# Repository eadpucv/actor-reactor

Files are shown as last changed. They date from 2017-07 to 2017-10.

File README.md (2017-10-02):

# Actor Reactor

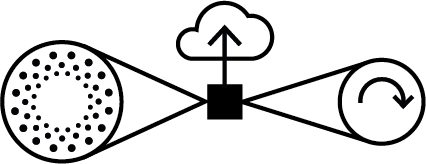
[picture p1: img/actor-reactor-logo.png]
Logo Actor Reactor


Actor Reactor es una unidad de interacción física compuesta de:  

1. Sensor (de proximidad)
2. Procesamiento y disponibilización Web de datos
3. Actuador (motor stepper)

Este proyecto se basa en la unidad [Actor-Reactor documenta 14](https://github.com/amereida/actor-re-actor) y extiende su diseño para espacios expositivos en general. Cada unidad percibe el entorno mediante un sensor de distancia y translada esta intensidad a un motor y a un servicio Web con los datos normalizados para control sonoro mediante [Pure Data](https://puredata.info/). El actuador, definido mediante un motor stepper, variará su configuración estructural y de transmisión de la energía mecánica, dependiendo de la naturaleza del objeto expuesto.

* ver [configuración actual en una planilla](https://docs.google.com/spreadsheets/d/1H8SptrEivwXtSlFbvr6E0EB0E-gABvcepRMJ9xA1qTE/edit?usp=sharing) 

### Participantes

* [Herbert Spencer](http://wiki.ead.pucv.cl/index.php/Herbert_Spencer), Diseño de Artefactos
* [Marcelo Araya](http://wiki.ead.pucv.cl/index.php/Marcelo_Araya), Diseño de Creaturas
* [Óscar Santis](https://soundcloud.com/oscarsantis), Diseño de sonido
* [Leonardo Aravena](http://wiki.ead.pucv.cl/index.php/Leonardo_Aravena), Diseño y fabricación dispositivos
* [Ismael Martinez](https://www.linkedin.com/in/ismael-martinez-8bb78ba3/), Diseño electrónico 

#### Taller de Construcción 4 de Diseño Industrial

Catalina Vergara, Camila Campos Leiva, Carolina González, Paz Orellana, Javier Andre Arancibia Romero, Javier Zambra, Sofía Soto, Ur Conejeros, Francisca Collarte Videla, Tamara Hidalgo Porzio, Doyma Henríquez Atlagić, María Ignacia Morales, Paula Sotomayor, Javiera Martinez Guajardo, Bastian Maluenda

#### Taller de Espacios Expositivos

#### Construido sobre

Este proyecto utiliza tecnologías libres y abierta de software y hardware. Este repositiorio documenta todos los aspectos necesarios para la replicación completa del proyecto.

* [Exposición: Artefactos y Creaturas](http://eadpucv.github.io/actor-reactor)
* [Plano y datos de la sala](http://eadpucv.github.io/actor-reactor/www)

Arduino
Raspberry
Pure Data
P5js

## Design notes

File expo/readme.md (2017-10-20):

# Expo Automata

Servicio Web de visualización de datos de los sensores y disponibilización para [Pure Data](https://puredata.info/).

##### Instrucciones para desabilitar salvapantallas y ahorro de energía

	sudo leafpad ~/.config/lxsession/LXDE-pi/autostart

add:

	@xset s 0 0
	@xset s noblank
	@xset s noexpose
	@xset dpms 0 0 0

##### Instrucciones para dejar un archivo autoejecutable al inicio

	leafpad superscript
	
Se crea y se edita el archivo superscript en la carpeta del usuario. El contenido debe ser el siguiente:

	#!/bin/bash
	/home/pi/path-to-app --run

Y en el archivo de inicio de LXDE:

	sudo leafpad ~/.config/lxsession/LXDE-pi/autostart

agregar al final:

	@/home/pi/superscript

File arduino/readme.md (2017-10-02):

##### Esquema de Control y Configuración en Menú de Pantalla

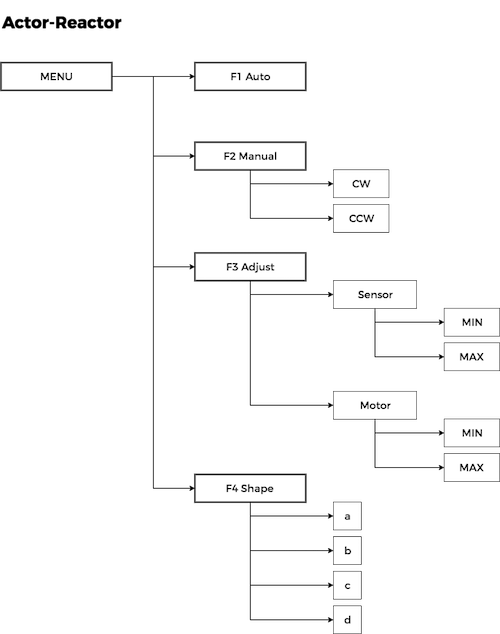
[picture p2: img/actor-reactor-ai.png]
Esquema de Control


Para configurar el módulo WIFI revise el [siguiente archivo](config_esp8266)

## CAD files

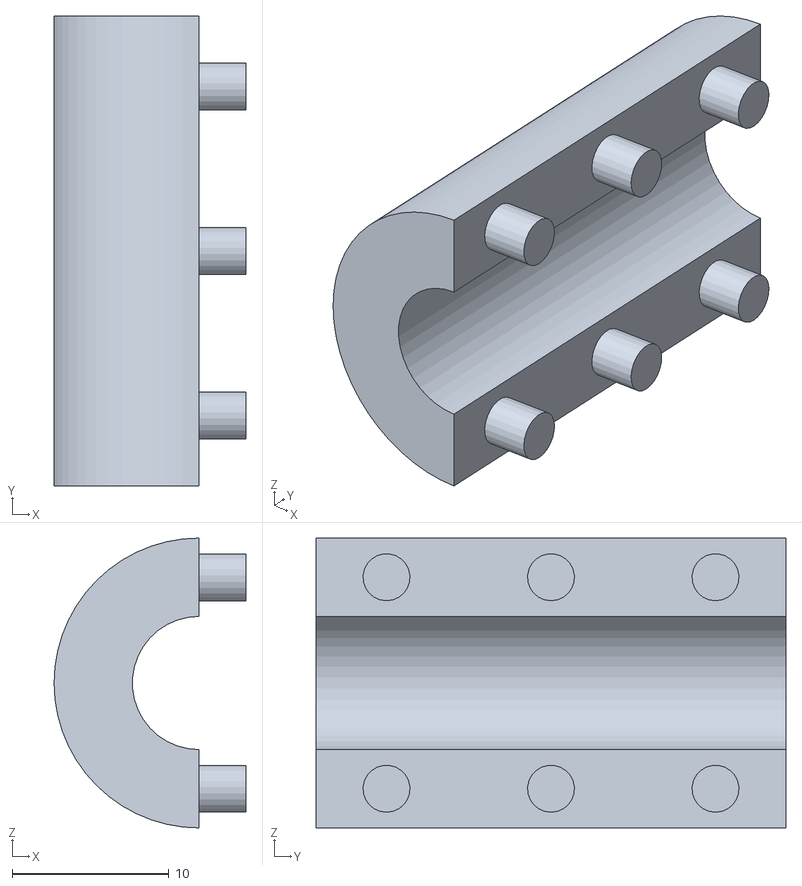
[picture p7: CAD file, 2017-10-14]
cnc/stl-3d/G7piezamacho.stl
12.2 x 30.0 x 18.5

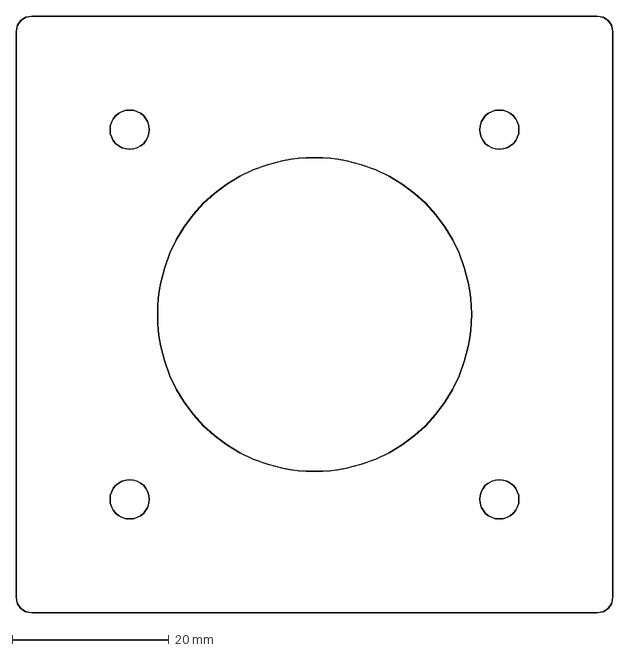
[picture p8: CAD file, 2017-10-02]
model/export/corte base motor.dxf
76.0 x 76.0 mm

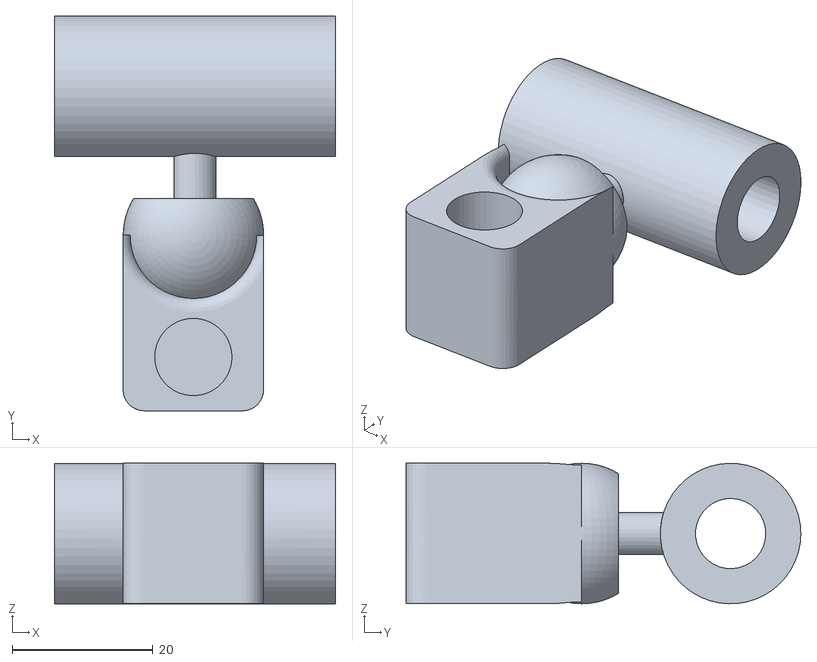
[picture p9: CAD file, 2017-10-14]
cnc/stl-3d/G7Rotula.stl
40.0 x 56.2 x 20.0

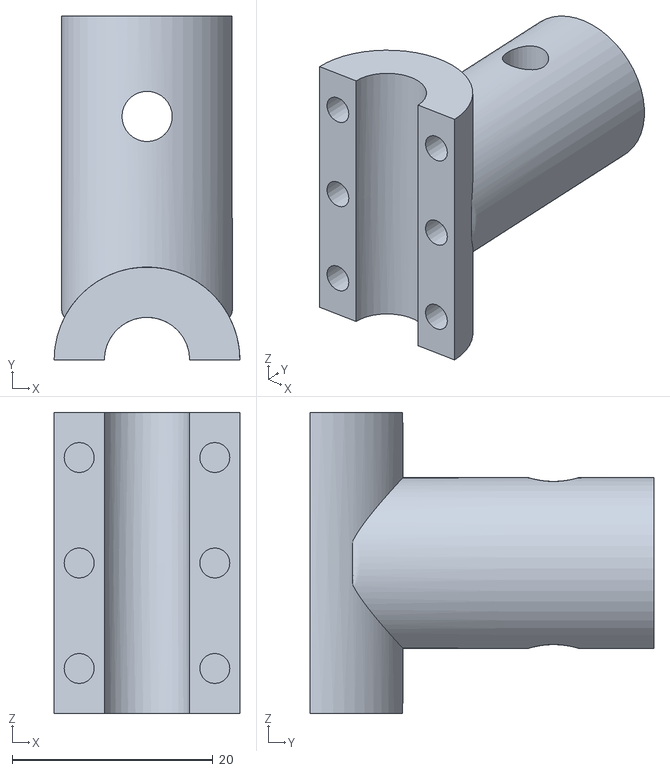
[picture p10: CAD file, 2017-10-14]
cnc/stl-3d/G7piezahembra.stl
18.5 x 34.2 x 30.0

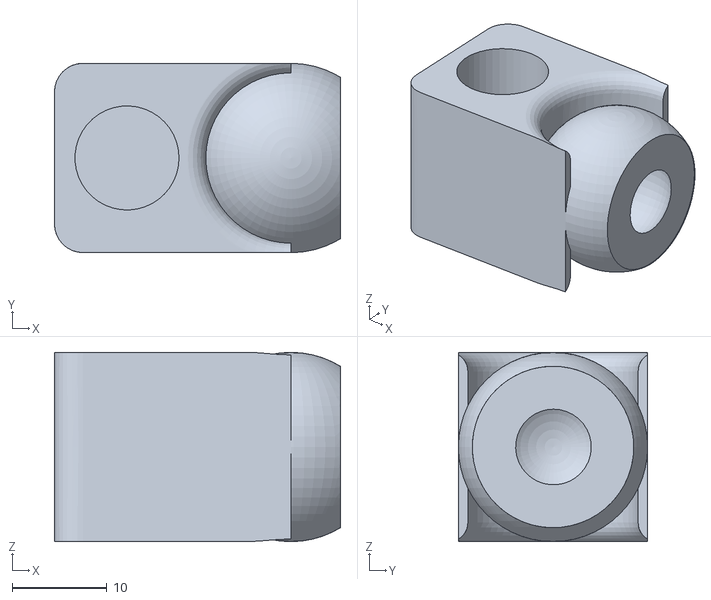
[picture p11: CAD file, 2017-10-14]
cnc/stl-3d/G7piezaB.stl
30.2 x 20.0 x 20.0

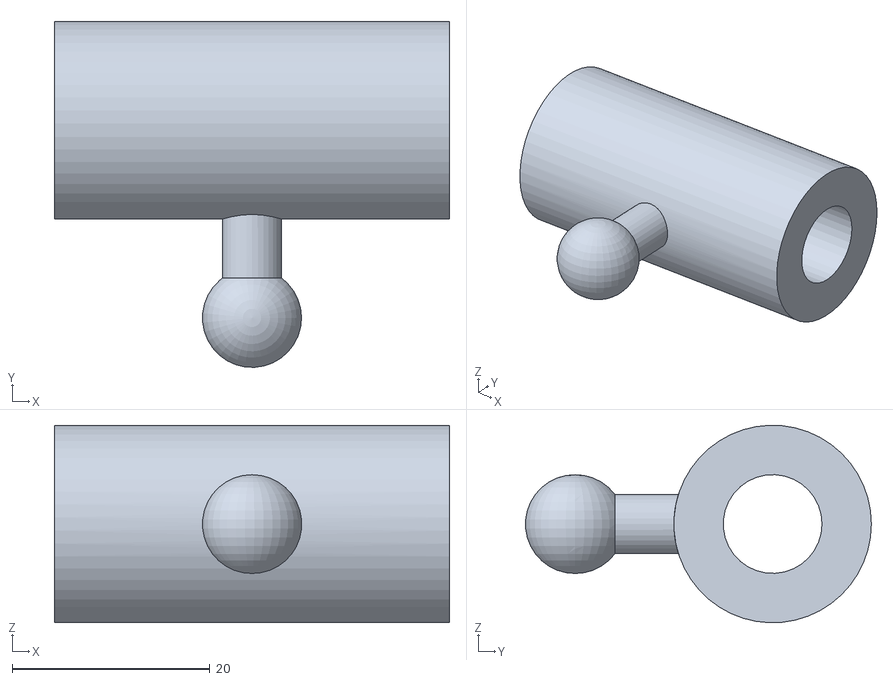
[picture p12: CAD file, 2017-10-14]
cnc/stl-3d/G7piezaA.stl
40.0 x 35.0 x 20.0

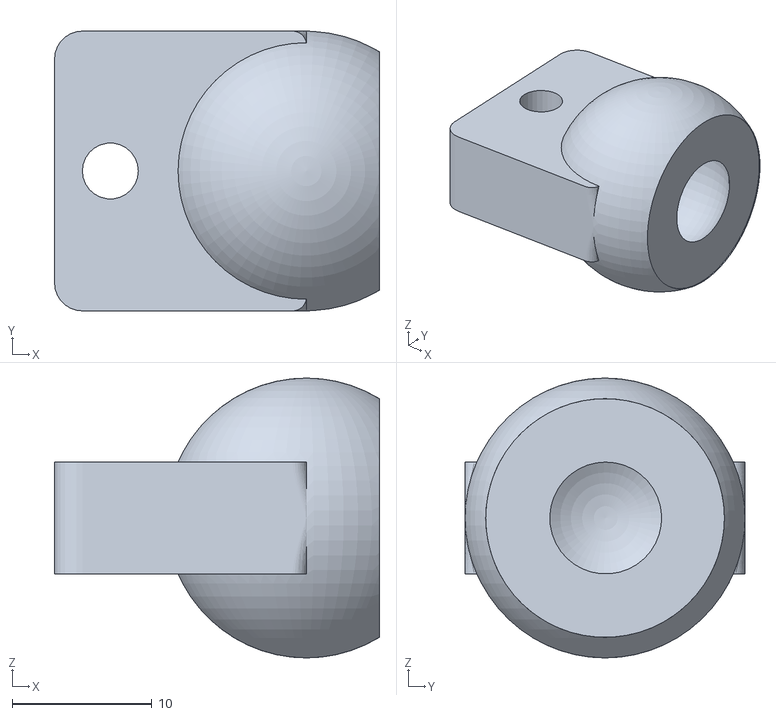
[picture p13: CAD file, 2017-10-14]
cnc/stl-3d/G1piezaB.stl
23.2 x 20.0 x 20.0

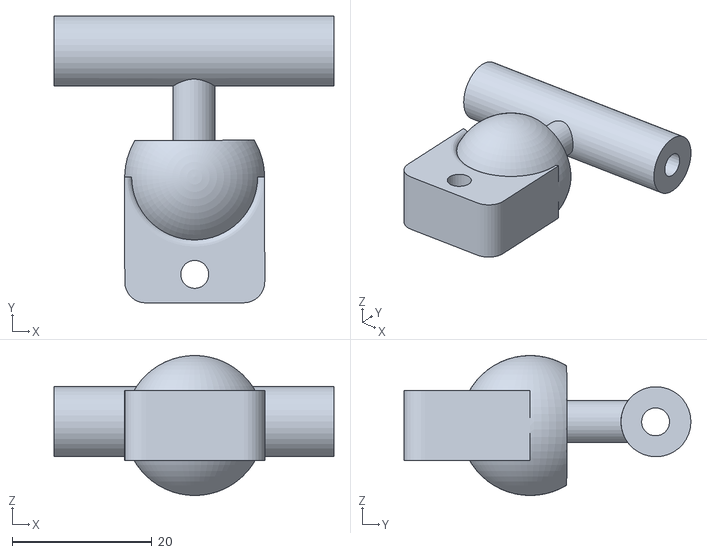
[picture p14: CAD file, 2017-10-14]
cnc/stl-3d/G1Rotula.stl
40.0 x 41.0 x 20.0

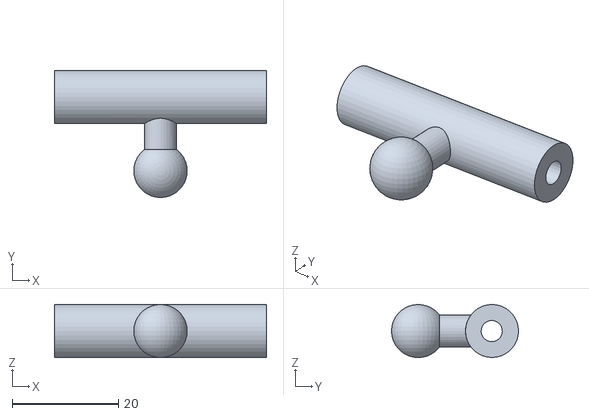
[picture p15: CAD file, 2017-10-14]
cnc/stl-3d/G1piezaA.stl
40.0 x 24.0 x 10.0

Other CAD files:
img/actor-reactor-logo.dxf
model/OldVersions/caja sensora.0011.iam
model/OldVersions/case.0009.iam
model/OldVersions/paleta expolra.0001.ipt
model/OldVersions/placa.0006.iam
model/OldVersions/vistas.0014.idw
model/caja sensora.iam
model/caja sensora/Design Accelerator/Bolted Connection1.iam
model/cas.iam
model/case.iam
model/case/Design Accelerator/Bolted Connection1.iam
model/case/OldVersions/despi.0002.ipn
model/case/OldVersions/tapa.0002.ipt
model/case/OldVersions/top.0016.ipt
model/case/OldVersions/traba cable.0004.ipt
model/case/base teclado.ipt
model/case/despi.ipn
model/case/remache.ipt
model/case/tapa.ipt
model/case/top.ipt
model/case/traba cable.ipt
model/componentes/Motor.ipt
model/componentes/OldVersions/Motor.0003.ipt
model/componentes/OldVersions/botonera.0001.ipt
model/componentes/OldVersions/conector mini usb.0001.ipt
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

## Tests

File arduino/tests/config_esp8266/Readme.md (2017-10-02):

## Tutorial configuración ESP8266

1. Extraer el jumper de la placa
1. Conectar el dispositivo ESP8266 a la placa
1. Subir el archivo *config_esp8266* a la placa haciendo click en la flecha superior izquierda encerrada en rojo
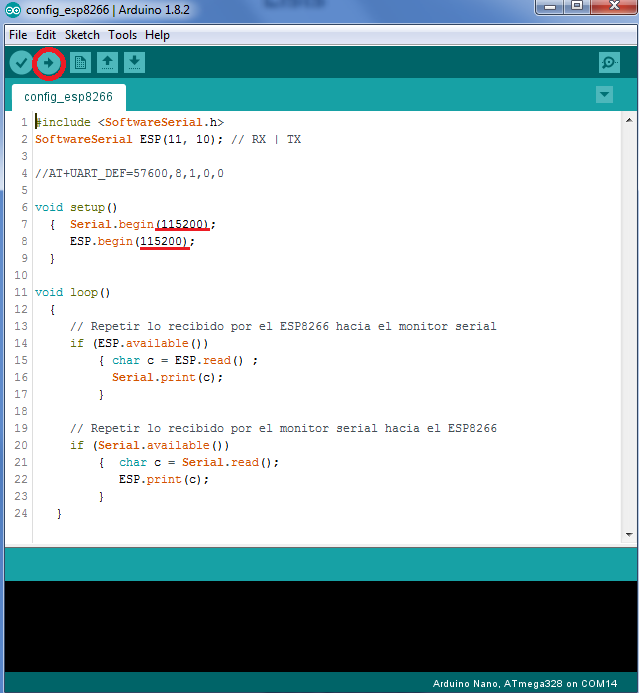
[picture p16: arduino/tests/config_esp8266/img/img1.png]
imagen1

1. Abrir el *Monitor Serial* haciendo click acá <br />
imagen2
1. Luego escribir AT y presionar ENTER. Debería aparecer **OK** en la pantalla como se muestra en la siguiente imagen<br />
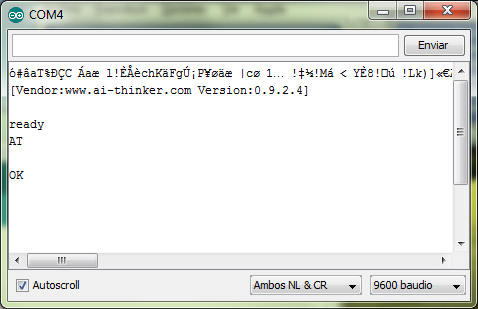
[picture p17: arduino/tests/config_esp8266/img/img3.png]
imagen3

1. Tras eso, se debe escribir el siguiente comando y luego ENTER "_AT+UART_DEF=57600,8,1,0,0_" Cabe destacar que debe ser sin comillas
1. Tan solo será necesario insertar el Jumper nuevamente en la placa. Después de eso el dispositivo estará correctamente configurado y listo para usarse en el programa principal

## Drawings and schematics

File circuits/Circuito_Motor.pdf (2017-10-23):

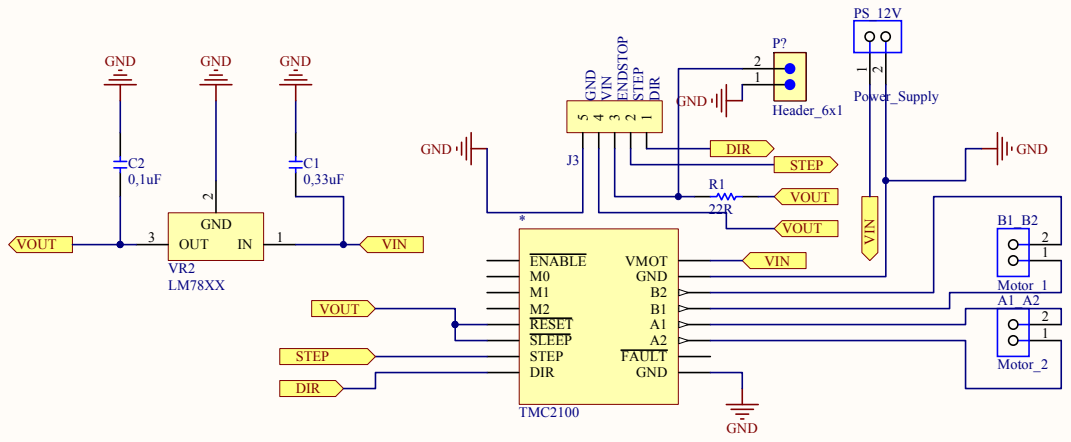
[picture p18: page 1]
Title; Size; Number; Revision; Date:; Sheet of; File:; motor.SchDoc; Drawn By:; ENABLE M0 M1 M2 RESET SLEEP STEP DIR; VMOT GND B2 B1 A1 A2 FAULT GND; TMC2100; VIN; ENDSTOP; STEP; DIR; GND; Motor_1; Motor_2 STEP; OUT 3; VOUT; Header_6x1 GND; Power_Supply

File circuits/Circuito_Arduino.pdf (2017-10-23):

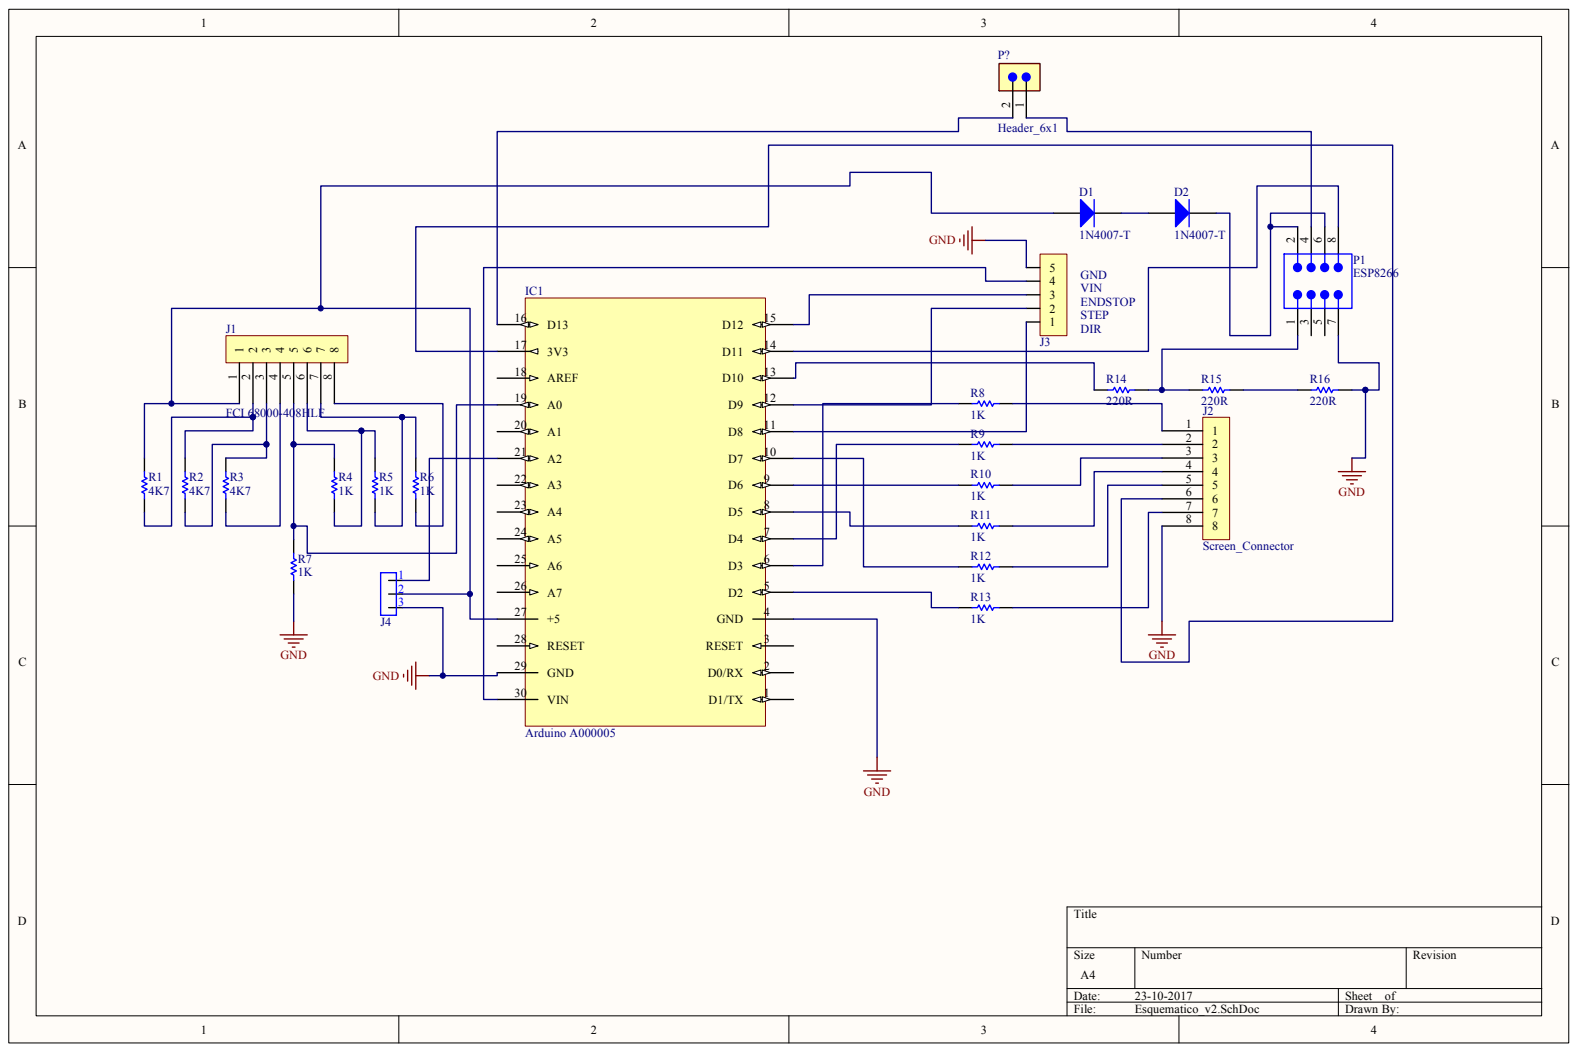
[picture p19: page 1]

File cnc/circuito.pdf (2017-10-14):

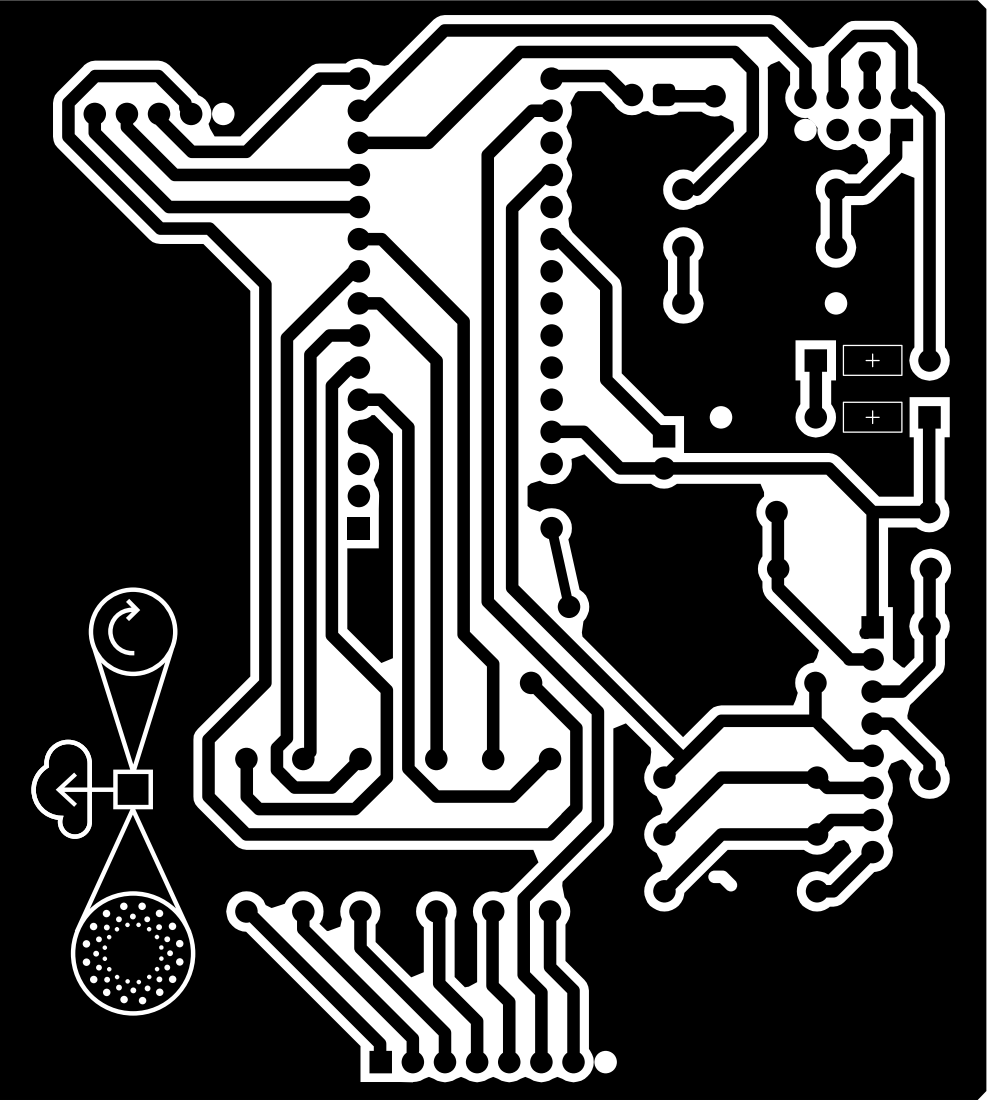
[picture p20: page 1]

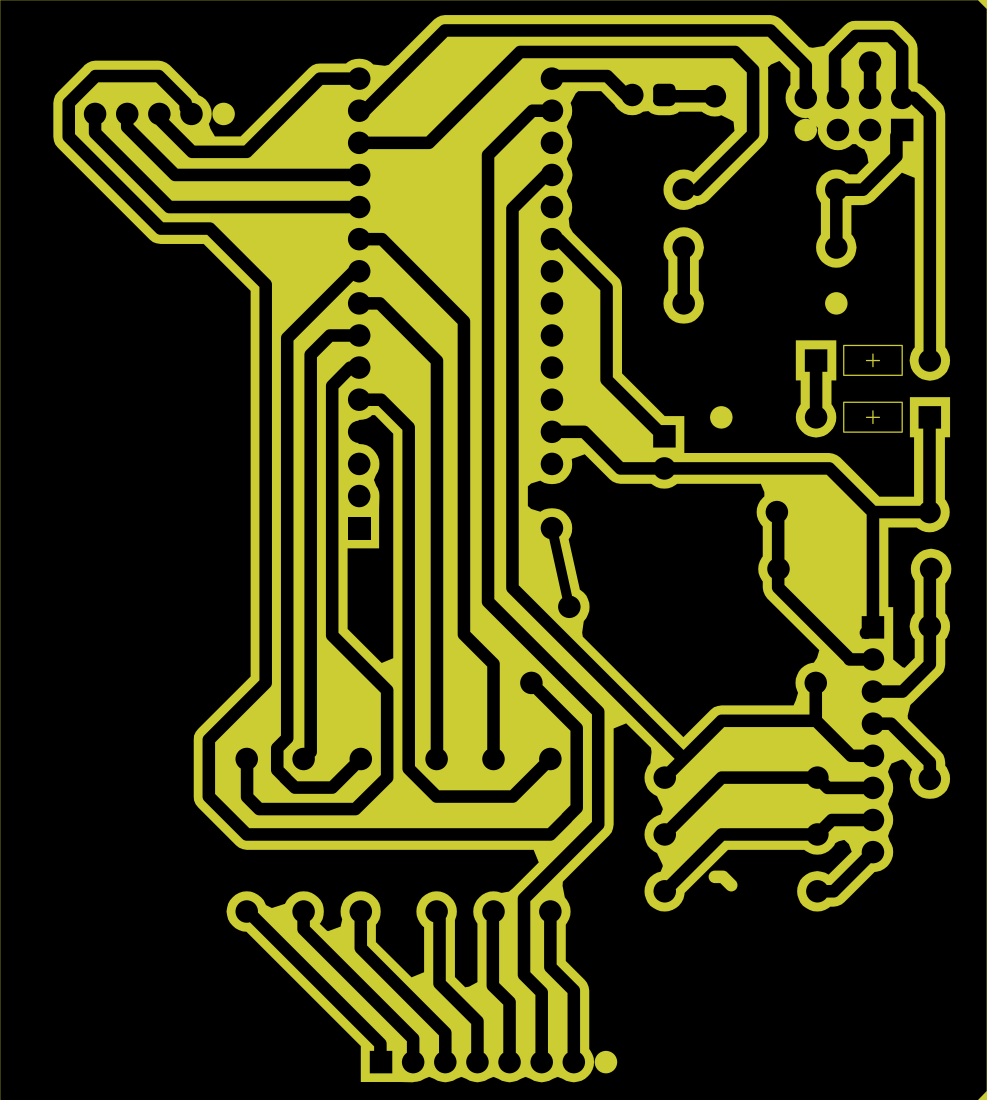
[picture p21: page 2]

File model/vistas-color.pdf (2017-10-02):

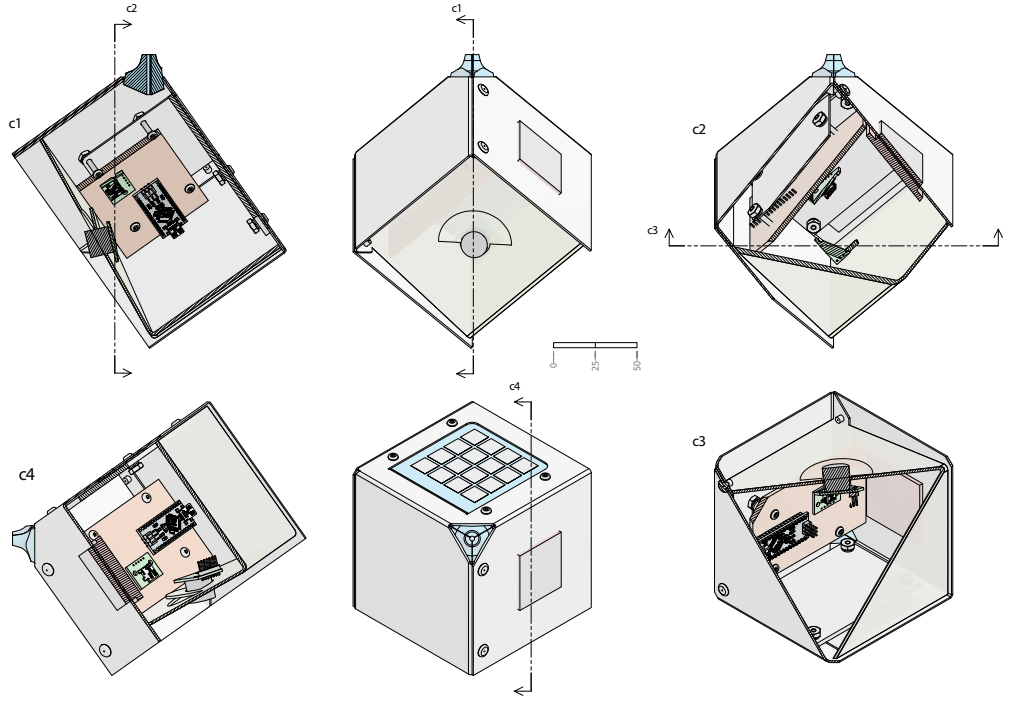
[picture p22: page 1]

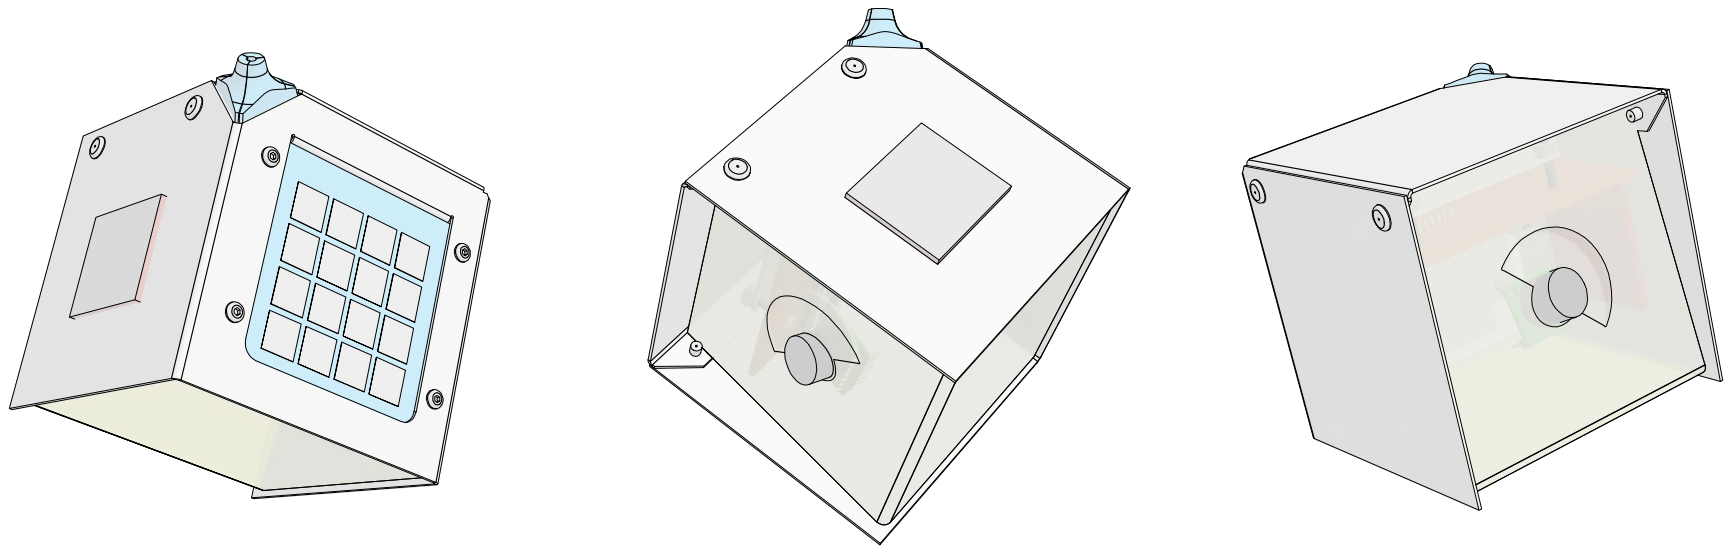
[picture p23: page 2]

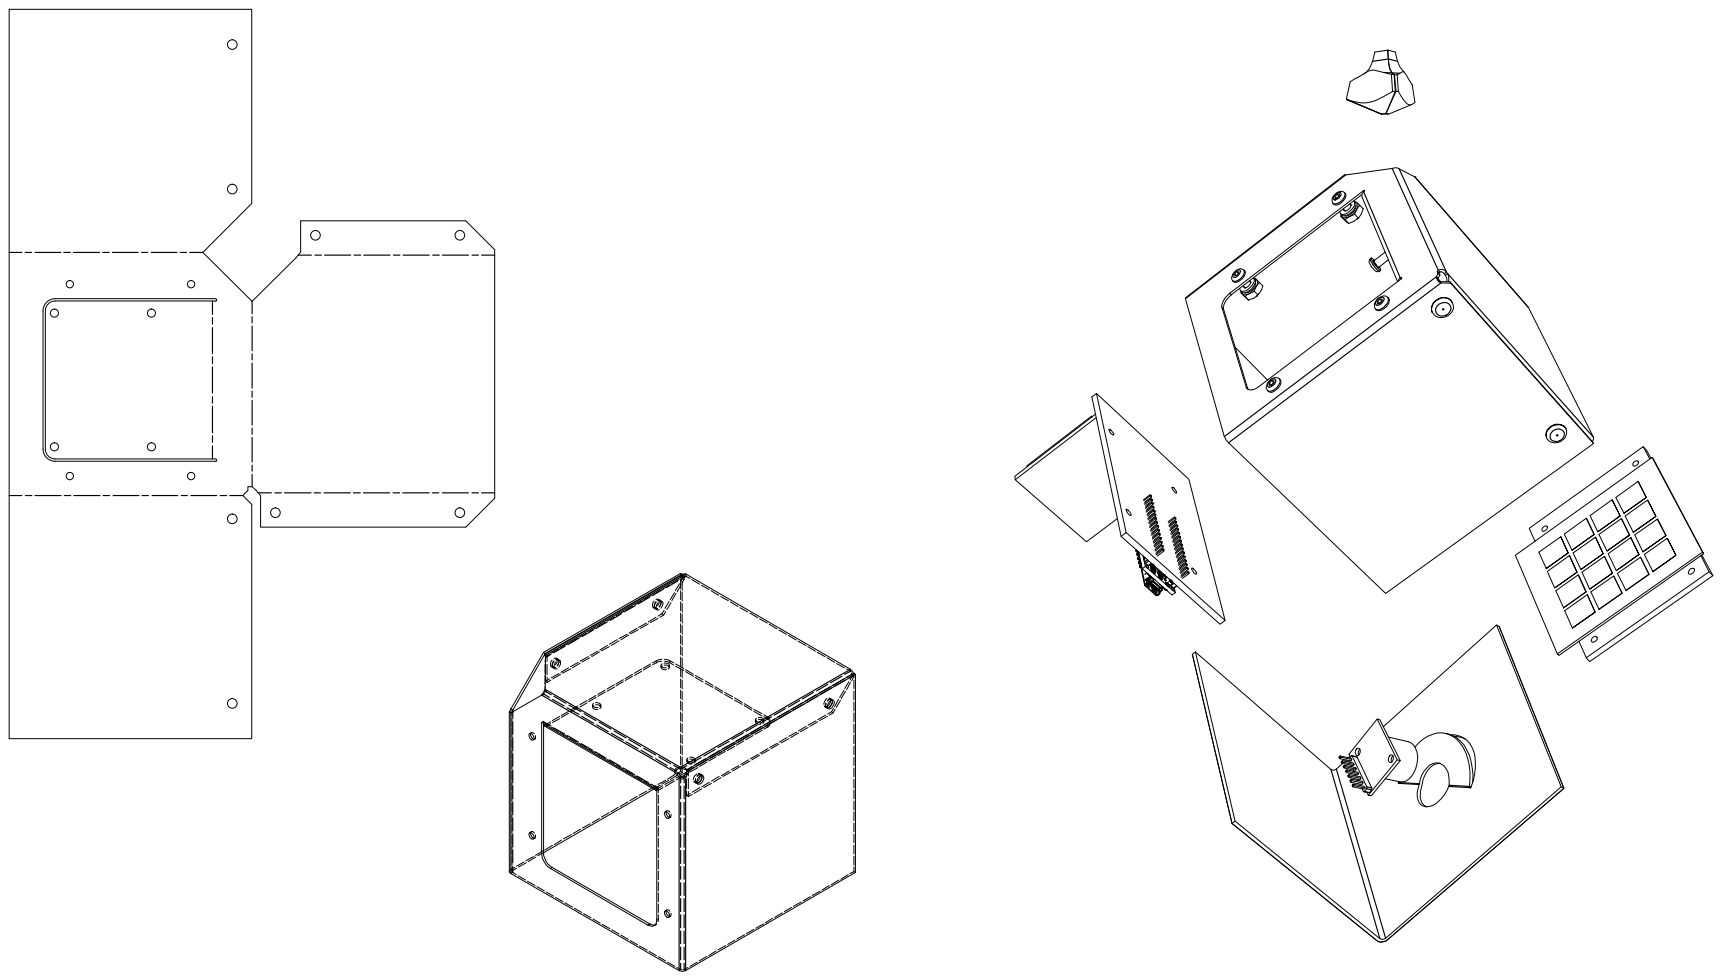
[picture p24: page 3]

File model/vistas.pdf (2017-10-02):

c

1

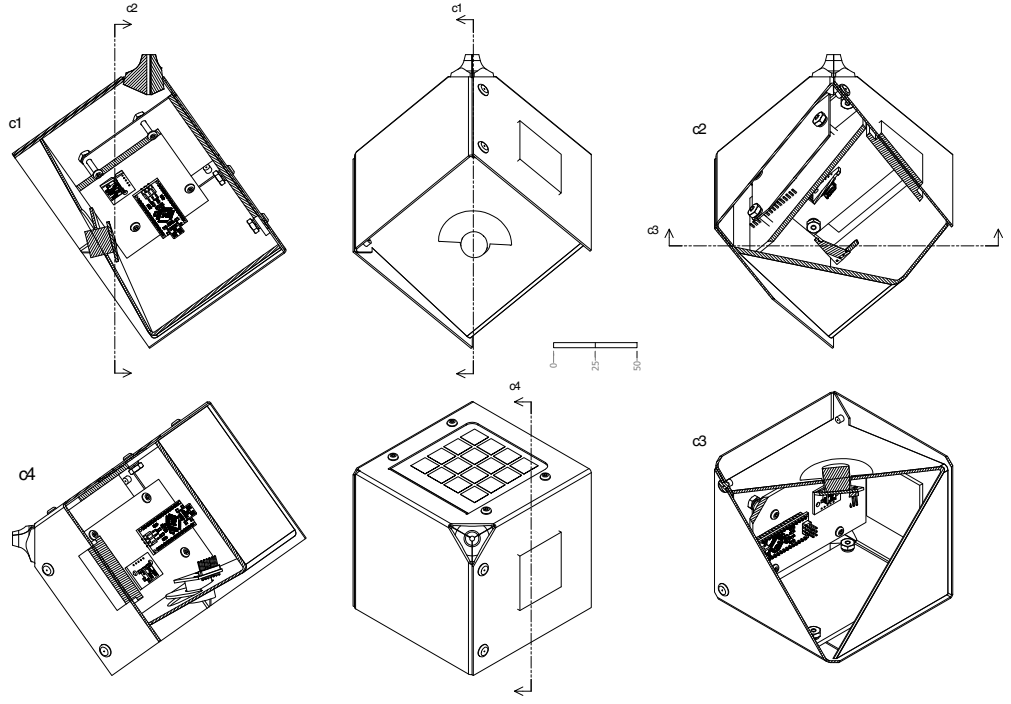
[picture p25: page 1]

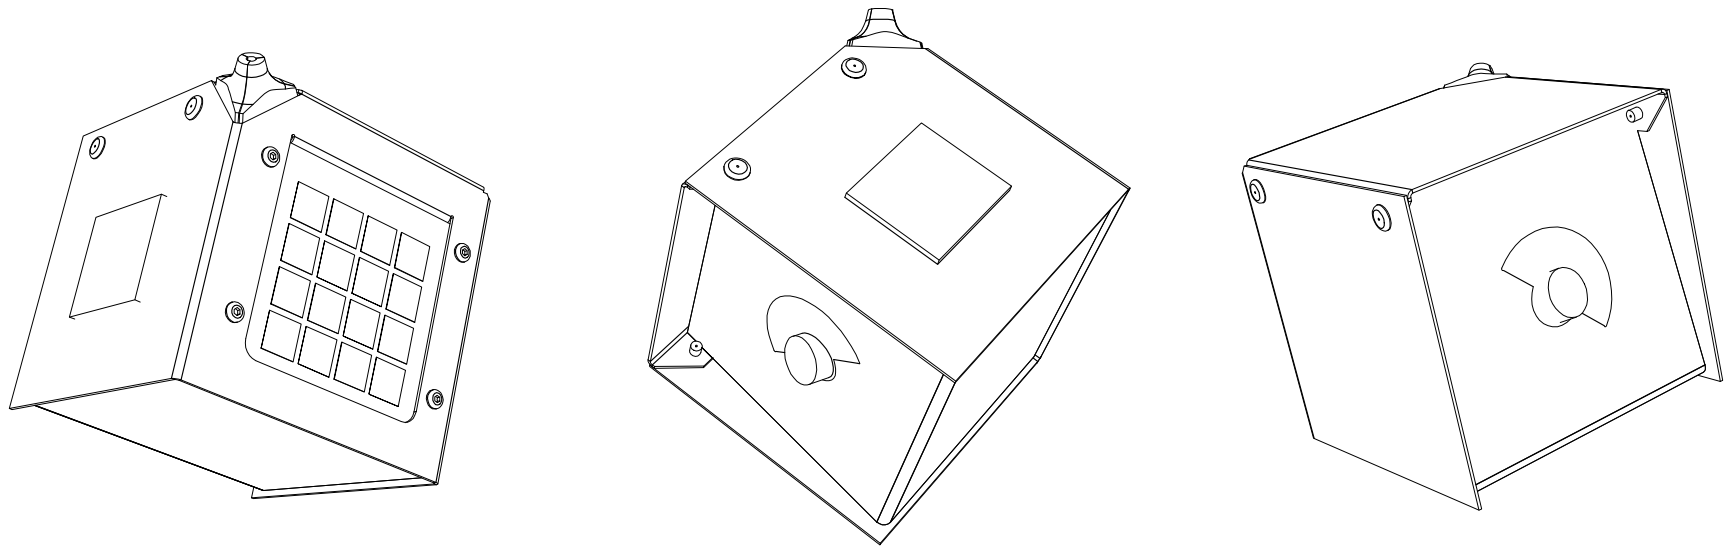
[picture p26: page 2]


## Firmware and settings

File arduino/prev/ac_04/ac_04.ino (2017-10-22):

/**

    Actor Reactor - CLAC
    Taller de Espacios Expositivos e[ad]
    Octubre 2017

    Serial Communication
*/

#include <SPI.h>
#include <Adafruit_GFX.h>
#include <Adafruit_PCD8544.h>
#include <OnewireKeypad.h>
#include <AccelStepper.h>
#include <EEPROM.h>
#include <SoftwareSerial.h>
#include <OSCMessage.h>

#define DIR_SENSOR_MIN 0
#define DIR_SENSOR_MAX 5
#define DIR_ACTUATOR_MIN 10
#define DIR_ACTUATOR_MAX 15

#define DIR_BEZIER_A 20
#define DIR_BEZIER_B 25
#define DIR_BEZIER_C 30
#define DIR_BEZIER_D 35


String NAME = "Creatura 1";


// #define WLAN_ADDR  "224.0.0.1"         // receiving Router ip
#define WLAN_ADDR  "192.168.0.1"          // receiving Router ip
#define PORT  1112
#define WLAN_SSID  "AC"                   // wifi SSID
#define WLAN_PASS  "actor-reactor"        // wifi password 


float min_sensor = 0, min_actuator = 0, max_sensor = 0, max_actuator = 0;
float bezier_A = 0, bezier_B = 0, bezier_C = 0, bezier_D = 0, motor_pos = 0, last_motor_pos;
float EPSILON = 9.999999747378752E-5f;
boolean variable;
boolean wifi = false;
int char_2_int=0;

char insert[10], serialdata;
char serialdata_motor[10];
int i = 0;
double normalize;
boolean mainmenu_disp = 0, resp;
boolean back = 0;
boolean endstop, endstop_activation = 0, endstop_position = 0;
boolean show_adjust = 0;

float sonar_read, acum_sonar_read;
int analog_counter = 0;
word previous_millis, actual_millis, diferencia;
float softenMotorPos = 0;

// Software SPI (slower updates, more flexible pin options):
// pin 7 - Serial clock out (SCLK)
// pin 6 - Serial data out (DIN)
// pin 5 - Data/Command select (D/C)
// pin 4 - LCD chip select (CS)
// pin 3 - LCD reset (RST)

Adafruit_PCD8544 display = Adafruit_PCD8544(7, 5, 6, 4, 3);

//AccelStepper stepper(AccelStepper::DRIVER, 9, 8); // CLK+(paso) -> pin 9 --- CW+(direccion) -> pin 8
AccelStepper stepper(2, 9, 8);

char KEYS[] = {
  '1', '2', '3', 'A',
  '4', '5', '6', 'B',
  '7', '8', '9', 'C',
  'Y', '0', 'N', 'D'
};

OnewireKeypad <Print, 16 > KP2(Serial, KEYS, 4, 4, A0, 4700, 1000, ExtremePrec );
SoftwareSerial wifiLink(11, 10);

boolean starting = true;  // para que se vaya a automático al partir

void setup () {
  Serial.begin(57600);
  pinMode(2, OUTPUT);
  pinMode(12, INPUT);
  wifiLink.begin(57600);
  Serial.setTimeout(10000);
  
  digitalWrite(4, 0);
  digitalWrite(2, 0);
  
  pinMode(13, OUTPUT);
  delay(10);
  pinMode(13, INPUT);

  stepper.setSpeed(150.0);
  stepper.setMaxSpeed(200.0);
  stepper.setAcceleration(100.0);
  stepper.setCurrentPosition(0);
  stepper.moveTo(motor_pos);

  resp = wifiLink.find("ready\r\n");
  wifiLink.println("AT+CWMODE=1");
  resp = wifiLink.find("OK\r\n");

  // connect to wifi

  wifiLink.println("AT+CIPMUX=1");
  resp = wifiLink.find("OK\r\n");
  wifiLink.print("AT+CIPSTART=4,\"UDP\",\"");
  wifiLink.print(WLAN_ADDR);
  wifiLink.print("\",54321,"); // osc port
  wifiLink.print(PORT);
  wifiLink.println(",0");
  resp = wifiLink.find("OK\r\n");
  wifiLink.setTimeout(1000);

  // display wifi status

  display.begin();
  display.clearDisplay();
  display.display();
  display.setContrast(60);
  display.setRotation(2);

 /*
  int attempts = 10;
  int count = 0;

  do {
    wifiLink.print("AT+CWJAP=\"");
    wifiLink.print(WLAN_SSID);
    wifiLink.print("\",\"");
    wifiLink.print(WLAN_PASS);
    wifiLink.println("\"");
    resp = wifiLink.find("OK\r\n");

    if (resp) {
      wifi = true;
      Serial.println(resp);
      Serial.println("wifi OK!!!");
      display.clearDisplay();
      display.display();
      display.println("wifi OK!!!");
      display.display();
      delay(1500);
      break;
      count = attempts;
    }
    
    Serial.print("wifi attempt\t");
    Serial.print(count);
    Serial.print(" / ");
    Serial.println(attempts);
    
    display.clearDisplay();
    display.display();
    display.println("wifi attempt ");
    display.print(count);
    display.print(" / ");
    display.print(attempts);
    display.display();
    delay(100);
    count ++;
    if(attempts == count){
      Serial.println("CONNECTION FAILED");
      }
  } while (count < attempts);
*/

  previous_millis = 0;
  actual_millis = millis();
  KP2.SetKeypadVoltage(4.7);

  EEPROM.get(DIR_SENSOR_MIN, min_sensor);
  EEPROM.get(DIR_SENSOR_MAX, max_sensor);
  EEPROM.get(DIR_ACTUATOR_MIN, min_actuator);
  EEPROM.get(DIR_ACTUATOR_MAX, max_actuator);

  EEPROM.get(DIR_BEZIER_A, bezier_A);
  EEPROM.get(DIR_BEZIER_B, bezier_B);
  EEPROM.get(DIR_BEZIER_C, bezier_C);
  EEPROM.get(DIR_BEZIER_D, bezier_D);

  write_eeprom(); // write default values if keypad not working

  Serial.println("done setup");
}

// position = 0 -> endstop al inicio
// position = 1 -> endstop al final

void endstop_action() {
  stepper.setCurrentPosition(0);
  if (last_motor_pos < motor_pos) {
    do {
      motor_pos--;
      stepper.moveTo(motor_pos);
      stepper.run();
    } while (digitalRead(12) == 0);
    stepper.runToNewPosition(-10);
    stepper.setCurrentPosition(0);
  }
  else if (last_motor_pos > motor_pos) {
    do {
      motor_pos++;
      stepper.moveTo(motor_pos);
      stepper.run();
    } while (digitalRead(12) == 0);
  }
  stepper.setCurrentPosition(0);
  motor_pos = 0;
}

void loop() {
  sonar_read = analogRead(A2) * 1.26;
  actual_millis = millis();
  diferencia = actual_millis - previous_millis;
  if (diferencia > 100) {
    previous_millis = actual_millis;
    mainmenu();
  }

  if (starting) automatic(); // vaya a automático al partir

  stepper.run();
  if ( Serial.available() ) {
    getSerial();
    Serial.println(serialdata);
    switch (serialdata) {

      /* F1 */
      case 'A':
        Serial.println("Automatic mode");
        memset(serialdata, 0, sizeof(serialdata));
        automatic();
        break;

      /* F2 */
      case 'B':
        Serial.println("Manual mode");
        memset(serialdata, 0, sizeof(serialdata));
        manual();
        break;

      /* F3 */
      case 'C':
        Serial.println("Adjust values");
        memset(serialdata, 0, sizeof(serialdata));
        adjust();
        break;

      /* F4 */
      case 'D':
        Serial.println("Bezier mode");
        memset(serialdata, 0, sizeof(serialdata));
        bezier();
        break;
    }
    
  }
}

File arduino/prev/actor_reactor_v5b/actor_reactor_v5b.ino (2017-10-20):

#include <SPI.h>
#include <Adafruit_GFX.h>
#include <Adafruit_PCD8544.h>
#include <OnewireKeypad.h>
#include <AccelStepper.h>
#include <EEPROM.h>
#include <SoftwareSerial.h>
#include <OSCMessage.h>

#define DIR_SENSOR_MIN 0
#define DIR_SENSOR_MAX 5
#define DIR_ACTUATOR_MIN 10
#define DIR_ACTUATOR_MAX 15

#define DIR_BEZIER_A 20
#define DIR_BEZIER_B 25
#define DIR_BEZIER_C 30
#define DIR_BEZIER_D 35

#define ID 1
#define WLAN_ADDR  "192.168.0.255"
#define PORT  1112
/*
#define WLAN_SSID  "MadLab"
#define WLAN_PASS  "12345678"
*/

#define WLAN_SSID  "AC"
#define WLAN_PASS  "actor-reactor"

float min_sensor = 0, min_actuator = 0, max_sensor = 0, max_actuator = 0;
float bezier_A = 0, bezier_B = 0, bezier_C = 0, bezier_D = 0, motor_pos = 0;
float EPSILON = 9.999999747378752E-5f;

// motor_soft 
float motor_soft = 0;
float A = 0.98;
float B = 0.02;

//EEPROM.get(DIR_SENSOR_MIN, min_sensor);
//EEPROM.get(DIR_SENSOR_MAX, max_sensor);
//EEPROM.get(DIR_ACTUATOR_MAX, max_actuator);
char insert[10];
int i = 0;
double normalize;
boolean mainmenu_disp = 0, resp;
boolean salir = 0;
boolean endstop = 1, endstop_activation = 0, endstop_position = 0;
boolean show_adjust = 0;
long motor_pos_previous = 0;
float sonar_read, acum_sonar_read, last_motor_pos;
int analog_counter = 0;
word previous_millis, actual_millis, diferencia;

// Software SPI (slower updates, more flexible pin options):
// pin 7 - Serial clock out (SCLK)
// pin 6 - Serial data out (DIN)
// pin 5 - Data/Command select (D/C)
// pin 4 - LCD chip select (CS)
// pin 3 - LCD reset (RST)
Adafruit_PCD8544 display = Adafruit_PCD8544(7, 5, 6, 4, 3);
AccelStepper stepper(AccelStepper::DRIVER, 9, 8); // CLK+(paso) -> pin 9 --- CW+(direccion) -> pin 8

char KEYS[] = {
  '1', '2', '3', 'A',
  '4', '5', '6', 'B',
  '7', '8', '9', 'C',
  'Y', '0', 'N', 'D'
};


OnewireKeypad <Print, 16 > KP2(Serial, KEYS, 4, 4, A0, 4700, 1000, ExtremePrec );
SoftwareSerial mySerial(11, 10);


void setup () {
  Serial.begin(57600);
  mySerial.begin(57600);

  Serial.setTimeout(10000);
  pinMode(12, INPUT);
  digitalWrite(4, 0);
  pinMode(13, OUTPUT);
  delay(10);
  pinMode(13, INPUT);
  resp = mySerial.find("ready\r\n");
  mySerial.println("AT+CWMODE=1");
  resp = mySerial.find("OK\r\n");

  
    do {
    mySerial.print("AT+CWJAP=\"");
    mySerial.print(WLAN_SSID);
    mySerial.print("\",\"");
    mySerial.print(WLAN_PASS);
    mySerial.println("\"");
    resp = mySerial.find("OK\r\n");
    Serial.println(resp);
    } while (!resp);
  

  mySerial.println("AT+CIPMUX=1");
  resp = mySerial.find("OK\r\n");
  mySerial.print("AT+CIPSTART=4,\"UDP\",\"");
  mySerial.print(WLAN_ADDR);
  mySerial.print("\",54321,");
  mySerial.print(PORT);
  mySerial.println(",0");
  resp = mySerial.find("OK\r\n");
  mySerial.setTimeout(1000);
  display.begin();
  display.setContrast(60);
  display.setRotation(2);
  display.display();
  
  stepper.setMaxSpeed(200.0);
  stepper.setAcceleration(10000.0);
  stepper.setCurrentPosition(0);
  stepper.moveTo(motor_pos);
  
  previous_millis = 0;
  actual_millis = millis();
  KP2.SetKeypadVoltage(4.7);
  
  EEPROM.get(DIR_SENSOR_MIN, min_sensor);
  EEPROM.get(DIR_SENSOR_MAX, max_sensor);
  EEPROM.get(DIR_ACTUATOR_MIN, min_actuator);
  EEPROM.get(DIR_ACTUATOR_MAX, max_actuator);

  EEPROM.get(DIR_BEZIER_A, bezier_A);
  EEPROM.get(DIR_BEZIER_B, bezier_B);
  EEPROM.get(DIR_BEZIER_C, bezier_C);
  EEPROM.get(DIR_BEZIER_D, bezier_D);
  Serial.println("pase setup");

}


float DoubleQuadraticBezier (float x, float a, float b, float c, float d) {
  // functionName = "Double Quadratic Bezier";
  // also see http://engineeringtraining.tpub.com/14069/css/14069_150.htm
  // produces mysterious values when a=0,b=1,c=0.667,d=0.417

  float xmid = (a + c) / 2.0;
  float ymid = (b + d) / 2.0;
  xmid = constrain (xmid, EPSILON, 1.0 - EPSILON);
  ymid = constrain (ymid, EPSILON, 1.0 - EPSILON);

  float y = 0;
  float om2a;
  float t;
  float xx;
  float aa;
  float bb;

  if (x <= xmid) {
    xx = x / xmid;
    aa = a / xmid;
    bb = b / ymid;
    om2a = 1.0 - 2.0 * aa;
    if (om2a == 0) {
      om2a = EPSILON;
    }
    t = (sqrt(aa * aa + om2a * xx) - aa) / om2a;
    y = (1.0 - 2.0 * bb) * (t * t) + (2 * bb) * t;
    y *= ymid;
  }
  else {
    xx = (x - xmid) / (1.0 - xmid);
    aa = (c - xmid) / (1.0 - xmid);
    bb = (d - ymid) / (1.0 - ymid);
    om2a = 1.0 - 2.0 * aa;
    if (om2a == 0) {
      om2a = EPSILON;
    }
    t = (sqrt(aa * aa + om2a * xx) - aa) / om2a;
    y = (1.0 - 2.0 * bb) * (t * t) + (2 * bb) * t;
    y *= (1.0 - ymid);
    y += ymid;
  }

  return y;
}

void adjust_A() {
  display.clearDisplay();
  display.display();

  display.setTextSize(1);
  display.setTextColor(BLACK);
  display.setCursor(0, 0);
  display.println("Insert number");
  display.display();
  while (!salir == 1) {

    if ( char key = KP2.Getkey() ) {
      if (KP2.Key_State() == PRESSED) {
        switch (key) {

          case 'Y':
            i = 0;
            salir = !salir;
            break;
          case '1':
            insert[i] = key;
            display.print(insert[i]);
            display.display();
            i++;
            break;
          case '2':
            insert[i] = key;
            display.print(insert[i]);
            display.display();
            i++;
            break;
          case '3':
            insert[i] = key;
            display.print(insert[i]);
            display.display();
            i++;
            break;
          case '4':
            insert[i] = key;
            display.print(insert[i]);
            display.display();
            i++;
            break;
          case '5':
            insert[i] = key;
            display.print(insert[i]);
            display.display();
            i++;
            break;
          case '6':
            insert[i] = key;
            display.print(insert[i]);
            display.display();
            i++;
            break;
          case '7':
            insert[i] = key;
            display.print(insert[i]);
            display.display();
            i++;
            break;
          case '8':
            insert[i] = key;
            display.print(insert[i]);
            display.display();
            i++;
            break;
          case '9':
            insert[i] = key;
            display.print(insert[i]);
            display.display();
            i++;
            break;
          case '0':
            insert[i] = key;
            display.print(insert[i]);
            display.display();
            i++;
            break;
        }
      }

    }
  }
  bezier_A = atof(insert);
  bezier_A = bezier_A / 1000;
  EEPROM.put(DIR_BEZIER_A, bezier_A);
  for ( int i = 0; i < sizeof(insert);  ++i )
    insert[i] = (char)0;
  salir = !salir;
}
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

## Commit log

2017-05-26 Add files via upload
    versión 2.0 del código.
    Incluye inicio de carrera y corrección en caso de desfases e
2017-07-27 varios
    nuejo js de visualización y readme
2017-08-14 Patch de Pure Data de síntesis fm
2017-08-14 puredata
    patches de estructuras sonoras
2017-08-24 Orden definitivo de carpetas. Test de módulos de control y módulos de sonido en Pure Data.
2017-08-24 Módulos de control en Pure Data.
2017-08-24 Módulos de control OSC
2017-08-24 Módulos de sonido en Pure Data
2017-08-25 Módulos de sonido
2017-08-31 modificación de ID
2017-09-07 Actualización de módulos
2017-09-07 orden para rasppi
2017-09-08 Módulo de control
2017-09-08 Módulo de sonido
2017-09-13 cnc
    archivos para routeado de las placas
    [actor-reactor-logo.dxf, logo.dxf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]
2017-09-14 Actualización
    Agrego actor-reactor v3 con fin de carrera y Wi-Fi comentado por temas de compatibilidad. También está la version sin comentar. Saludos!
2017-09-16 Actualización
    Recordar subir la última actualización a los dispositivos
2017-09-27 Cambio de Readme
2017-09-27 modelos inventor
    [102 RESISTOR PACK.ipt, 15pin_header__.ipt, 16mhz crystal - measured.ipt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]
2017-09-29 módulos de control
2017-10-01 ejemplos de síntesis
2017-10-02 ajustes de archivos readme
    [schematic_global.fzz]
2017-10-03 mòdulos de trabajo
2017-10-03 módulos de trabajo
2017-10-04 módulos de desarrollo
2017-10-09 arreglo de ip, puerto y osc_id
    [actor_reactor_v3_no_wifi_fixed_eprom_hs.ino, actor_reactor_v4b.ino]
2017-10-09 counter
    se define un número máximo de intentos de conexión
2017-10-10 arduino ip, id_osc
2017-10-11 1,2
    Modificando 1 y 2. preparando el 3
2017-10-12 mòdulos de sonido cambios
2017-10-13 módulos de control y sonido
2017-10-14 sónido y comando de inicio
2017-10-16 desde raspberry pi
2017-10-16 readme de expo
2017-10-17 módulos de sonido definitivos
2017-10-19 IP de router en arduino
2017-10-19 ajuste módulos de sonido
2017-10-20 última versión de la proyección
2017-10-22 módulos de sonido plan B
2017-10-27 ahuste para cuerpo 5 (pulmón)
    que su rutina conste de 2 respiraciones
2017-11-07 forma de ondas
2018-07-31 ejemplos de análisis
